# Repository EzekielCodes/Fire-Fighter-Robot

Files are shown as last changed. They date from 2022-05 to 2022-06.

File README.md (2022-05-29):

# 2122PROJBRANDBLUSROBOT

## Getting started

To make it easy for you to get started with GitLab, here's a list of recommended next steps.

Already a pro? Just edit this README.md and make it your own. Want to make it easy? [Use the template at the bottom](#editing-this-readme)!

## Add your files

- [ ] [Create](https://docs.gitlab.com/ee/user/project/repository/web_editor.html#create-a-file) or [upload](https://docs.gitlab.com/ee/user/project/repository/web_editor.html#upload-a-file) files
- [ ] [Add files using the command line](https://docs.gitlab.com/ee/gitlab-basics/add-file.html#add-a-file-using-the-command-line) or push an existing Git repository with the following command:

```
cd existing_repo
git remote add origin https://gitlab.com/ikdoeict/toluwani.akindele/2122projbrandblusrobot.git
git branch -M main
git push -uf origin main
```

## Integrate with your tools

- [ ] [Set up project integrations](https://gitlab.com/ikdoeict/toluwani.akindele/2122projbrandblusrobot/-/settings/integrations)

## Collaborate with your team

- [ ] [Invite team members and collaborators](https://docs.gitlab.com/ee/user/project/members/)
- [ ] [Create a new merge request](https://docs.gitlab.com/ee/user/project/merge_requests/creating_merge_requests.html)
- [ ] [Automatically close issues from merge requests](https://docs.gitlab.com/ee/user/project/issues/managing_issues.html#closing-issues-automatically)
- [ ] [Enable merge request approvals](https://docs.gitlab.com/ee/user/project/merge_requests/approvals/)
- [ ] [Automatically merge when pipeline succeeds](https://docs.gitlab.com/ee/user/project/merge_requests/merge_when_pipeline_succeeds.html)

## Test and Deploy

Use the built-in continuous integration in GitLab.

- [ ] [Get started with GitLab CI/CD](https://docs.gitlab.com/ee/ci/quick_start/index.html)
- [ ] [Analyze your code for known vulnerabilities with Static Application Security Testing(SAST)](https://docs.gitlab.com/ee/user/application_security/sast/)
- [ ] [Deploy to Kubernetes, Amazon EC2, or Amazon ECS using Auto Deploy](https://docs.gitlab.com/ee/topics/autodevops/requirements.html)
- [ ] [Use pull-based deployments for improved Kubernetes management](https://docs.gitlab.com/ee/user/clusters/agent/)
- [ ] [Set up protected environments](https://docs.gitlab.com/ee/ci/environments/protected_environments.html)

***

# Editing this README

When you're ready to make this README your own, just edit this file and use the handy template below (or feel free to structure it however you want - this is just a starting point!).  Thank you to [makeareadme.com](https://www.makeareadme.com/) for this template.

## Suggestions for a good README
Every project is different, so consider which of these sections apply to yours. The sections used in the template are suggestions for most open source projects. Also keep in mind that while a README can be too long and detailed, too long is better than too short. If you think your README is too long, consider utilizing another form of documentation rather than cutting out information.

## Name
Choose a self-explaining name for your project.

## Description
Let people know what your project can do specifically. Provide context and add a link to any reference visitors might be unfamiliar with. A list of Features or a Background subsection can also be added here. If there are alternatives to your project, this is a good place to list differentiating factors.

## Badges
On some READMEs, you may see small images that convey metadata, such as whether or not all the tests are passing for the project. You can use Shields to add some to your README. Many services also have instructions for adding a badge.

## Visuals
Depending on what you are making, it can be a good idea to include screenshots or even a video (you'll frequently see GIFs rather than actual videos). Tools like ttygif can help, but check out Asciinema for a more sophisticated method.

## Installation
Within a particular ecosystem, there may be a common way of installing things, such as using Yarn, NuGet, or Homebrew. However, consider the possibility that whoever is reading your README is a novice and would like more guidance. Listing specific steps helps remove ambiguity and gets people to using your project as quickly as possible. If it only runs in a specific context like a particular programming language version or operating system or has dependencies that have to be installed manually, also add a Requirements subsection.

## Usage
Use examples liberally, and show the expected output if you can. It's helpful to have inline the smallest example of usage that you can demonstrate, while providing links to more sophisticated examples if they are too long to reasonably include in the README.

## Support
Tell people where they can go to for help. It can be any combination of an issue tracker, a chat room, an email address, etc.

## Roadmap
If you have ideas for releases in the future, it is a good idea to list them in the README.

## Contributing
State if you are open to contributions and what your requirements are for accepting them.

For people who want to make changes to your project, it's helpful to have some documentation on how to get started. Perhaps there is a script that they should run or some environment variables that they need to set. Make these steps explicit. These instructions could also be useful to your future self.

You can also document commands to lint the code or run tests. These steps help to ensure high code quality and reduce the likelihood that the changes inadvertently break something. Having instructions for running tests is especially helpful if it requires external setup, such as starting a Selenium server for testing in a browser.

## Authors and acknowledgment
Show your appreciation to those who have contributed to the project.

## License
For open source projects, say how it is licensed.

## Project status
If you have run out of energy or time for your project, put a note at the top of the README saying that development has slowed down or stopped completely. Someone may choose to fork your project or volunteer to step in as a maintainer or owner, allowing your project to keep going. You can also make an explicit request for maintainers.

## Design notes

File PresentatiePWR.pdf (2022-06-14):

# BESTUURBARE BRANDBLUSROBOT

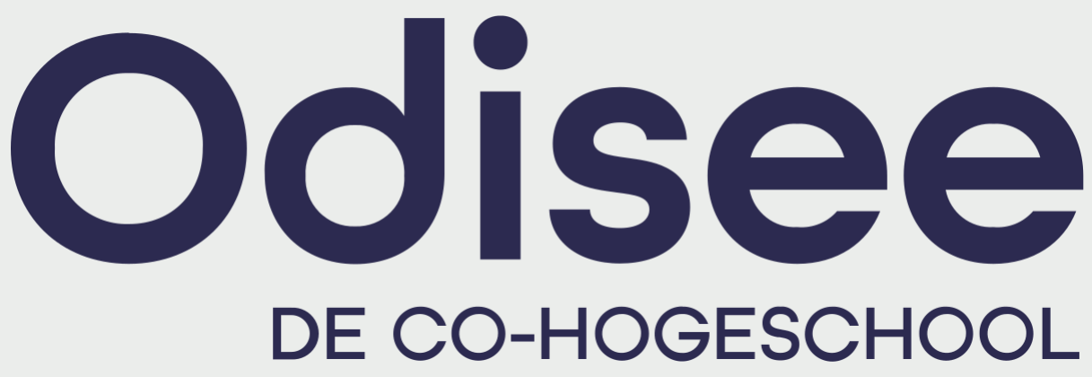
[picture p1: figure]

## Toluwani Akindele

## Vito Beké

## Michiel Decrock

## Lukas Rabaey

B es tuu r ba r e b randbl us r o bo t | 13-06-2022 | 1

## Project & wetenschappelijk rapporteren

## Groep: ICTEO12

# Inhoud

## - Besturing / aandrijving

## - Sensoren

## - Visualisatie, app

## - Waterreservoir

## - PCB

## - Lasercutten

## - Problemen

## - Optimalisatie

## - Demo

B es tuu r ba r e b ran dbl us r o bo t | 13-06-2022 | 2

# Besturing / aandrijving

## - PS2-controller

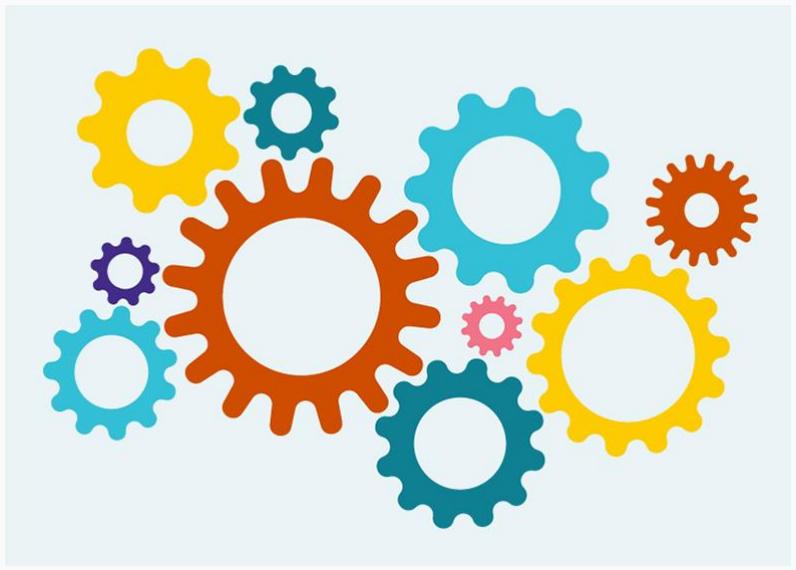
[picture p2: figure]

## - DC-motor

## - Stappenmotor

## - Waterpomp

B es tuu r ba r e b ran dbl us r o bo t | 13-06-2022 | 3

# PS2-controller

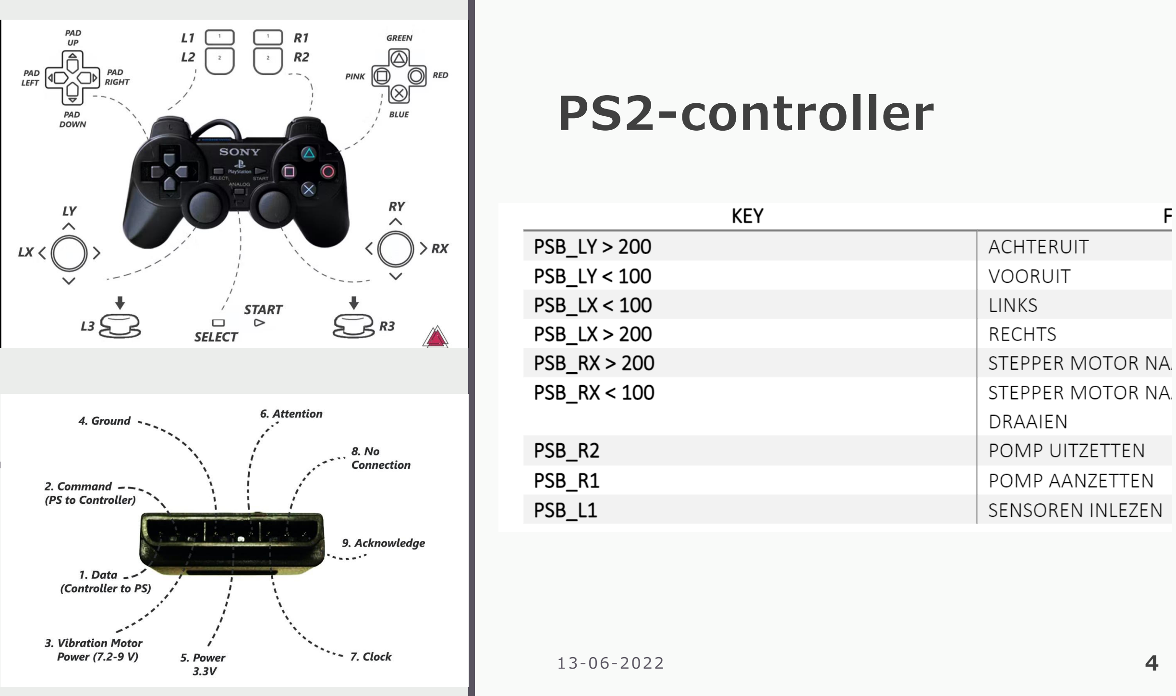
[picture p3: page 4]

13-06-2022 | 4

# DC-motor

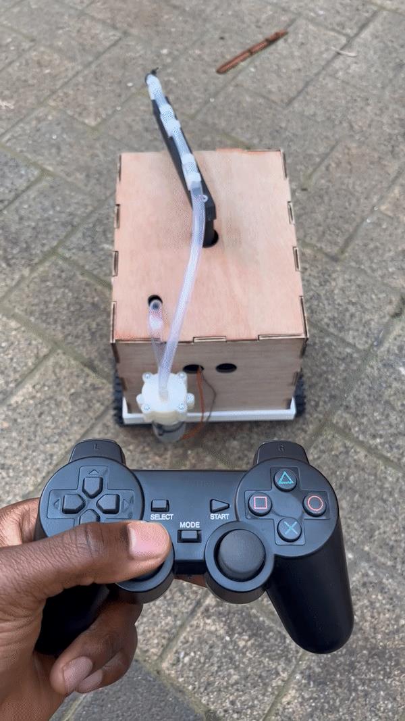
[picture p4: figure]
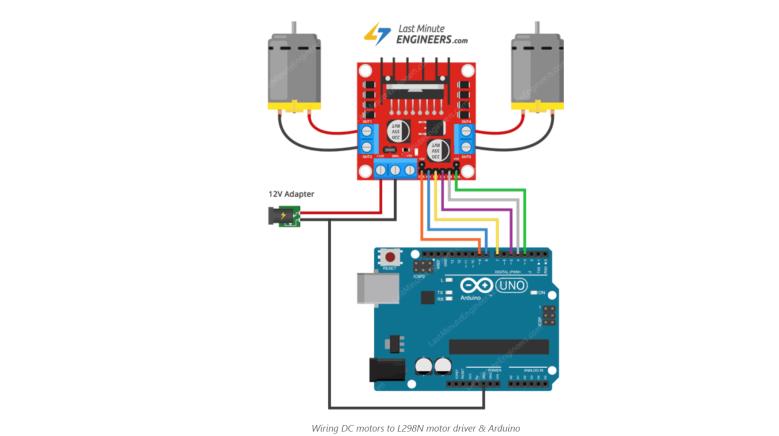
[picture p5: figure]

# Stappenmotor

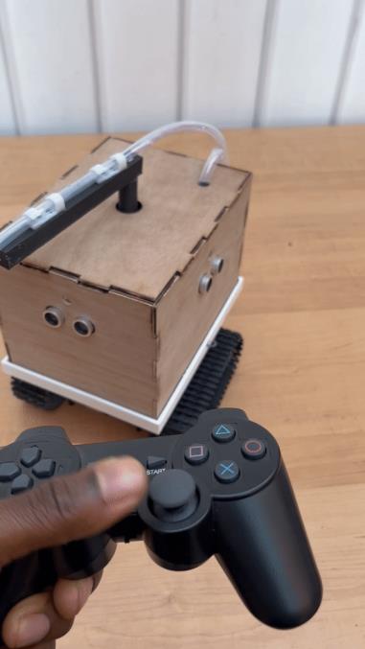
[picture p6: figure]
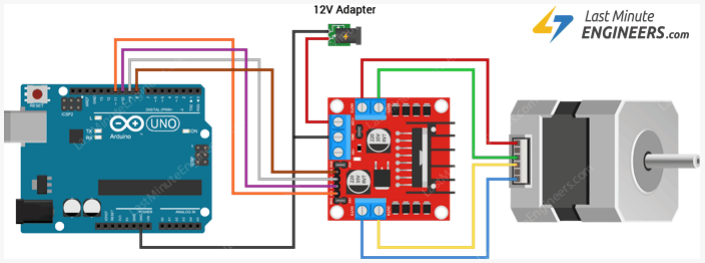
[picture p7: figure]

# Waterpomp

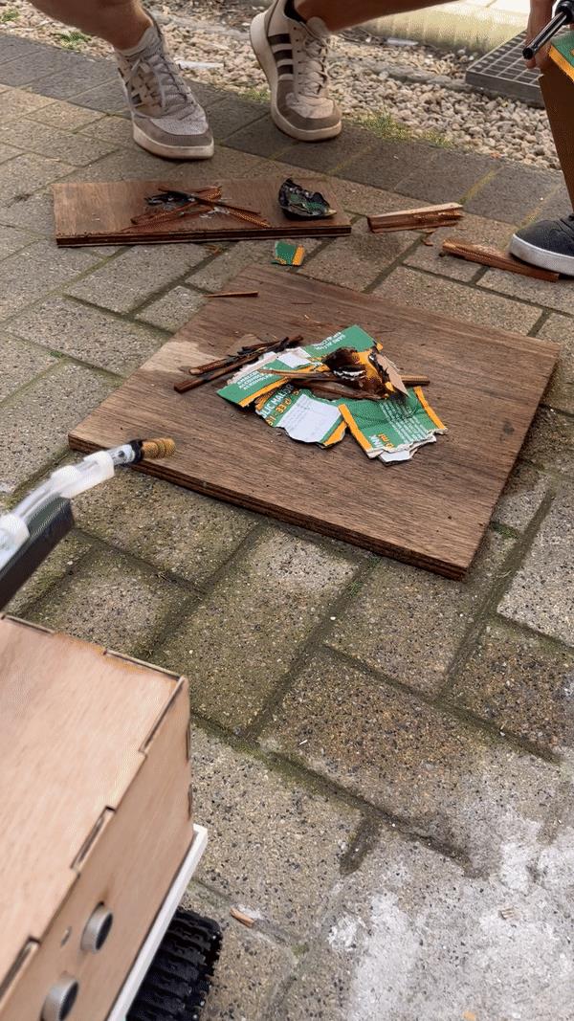
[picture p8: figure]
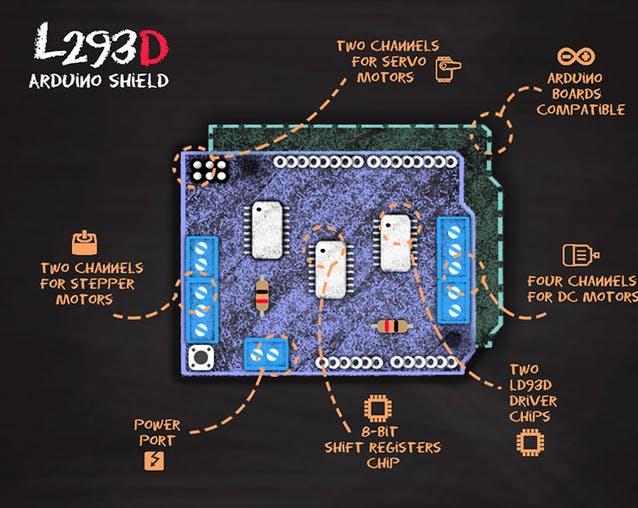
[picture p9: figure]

# Sensoren

## - HC-SR05 ultrasonic

## sensor

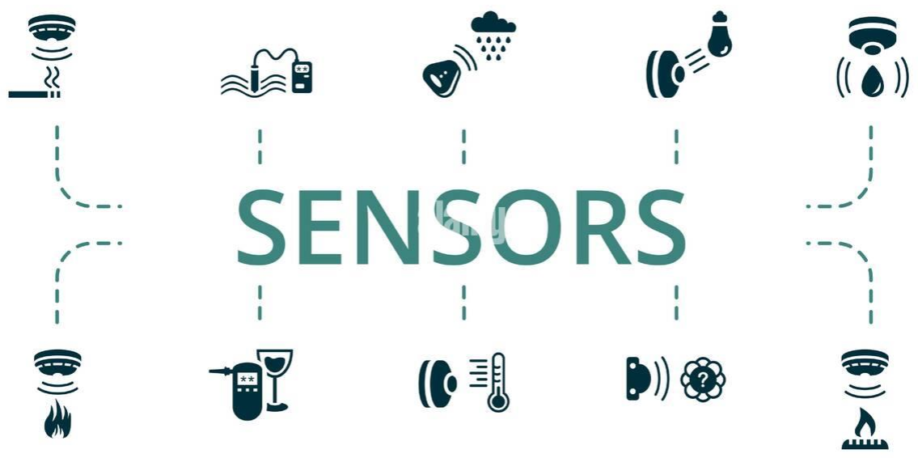
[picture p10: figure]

## - MLX90614

B es tuu r ba r e b ran dbl us r o bo t | 13-06-2022 | 8

# HC-SR05 ultrasonic sensor

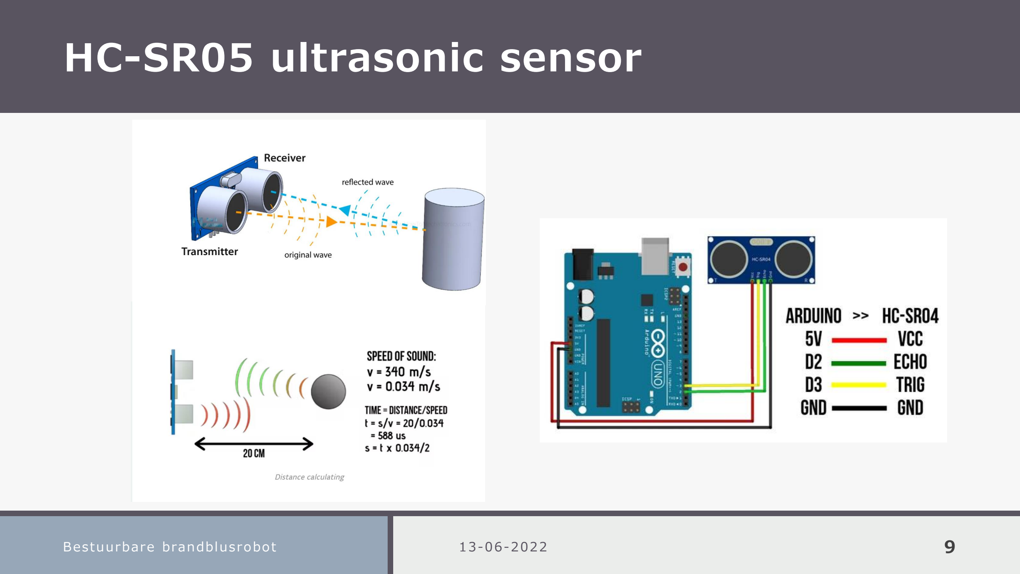
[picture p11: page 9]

# MLX90614

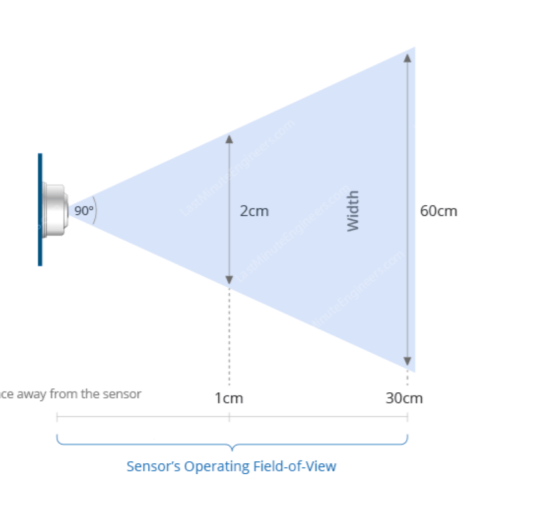
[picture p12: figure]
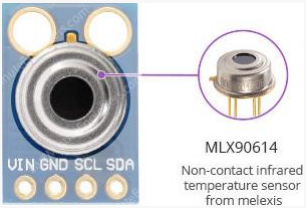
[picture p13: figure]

## - Visualisatie

# - App

- HC-05-

## bluetoothmodule

B es tuu r ba r e b ran dbl us r o bo t | 13-06-2022 | 11

# Visualisatie / app

# Visualisatie

## Connectiemethode: Bluetooth

## - goedkoop

## - ef ficiënter energieverbruik

## (tegenover wifi)

## - PoC: geen groot

## signaalbereik nodig

# App

## - MIT App Inventor

## - eenvoudig programmeren

## - Android app

# App

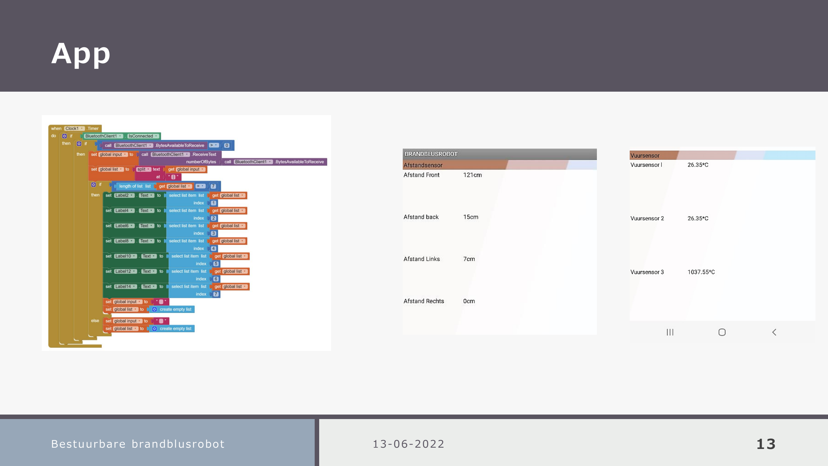
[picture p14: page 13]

# Bluetoothmodule

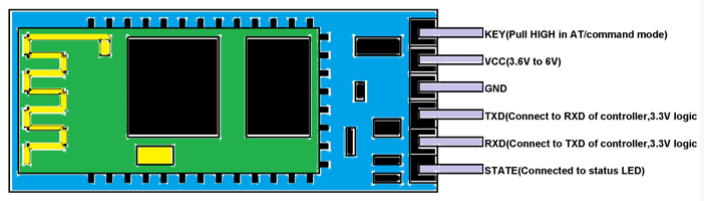
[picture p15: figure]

## HC-05-bluetoothmodule

## - Sof twareSerial library

## - Sensoren → Arduino →

## BT module → App

## (component)

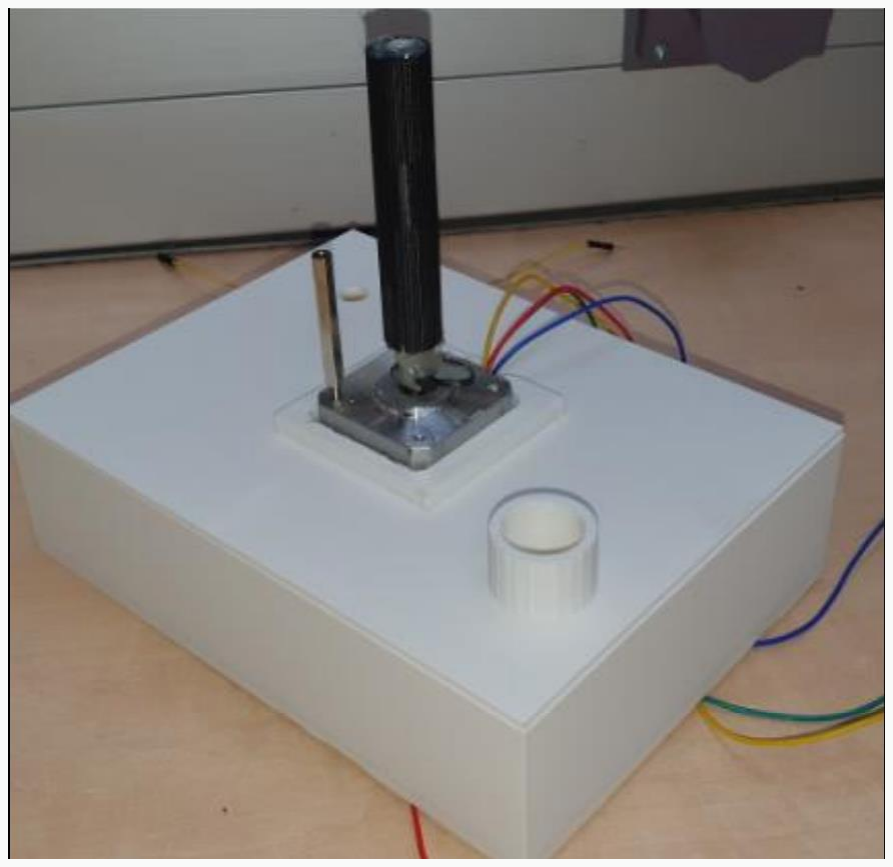
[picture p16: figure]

B es tuu r ba r e b ran dbl us r o bo t | 13-06-2022 | 15

# Waterreservoir

# Waterreservoir

## - PLA

## - 5,0 mm dikte buitenranden

## - Nozzle: 0,5 mm

## - Siliconenspray

## - Inhoud: +/- 0,5L

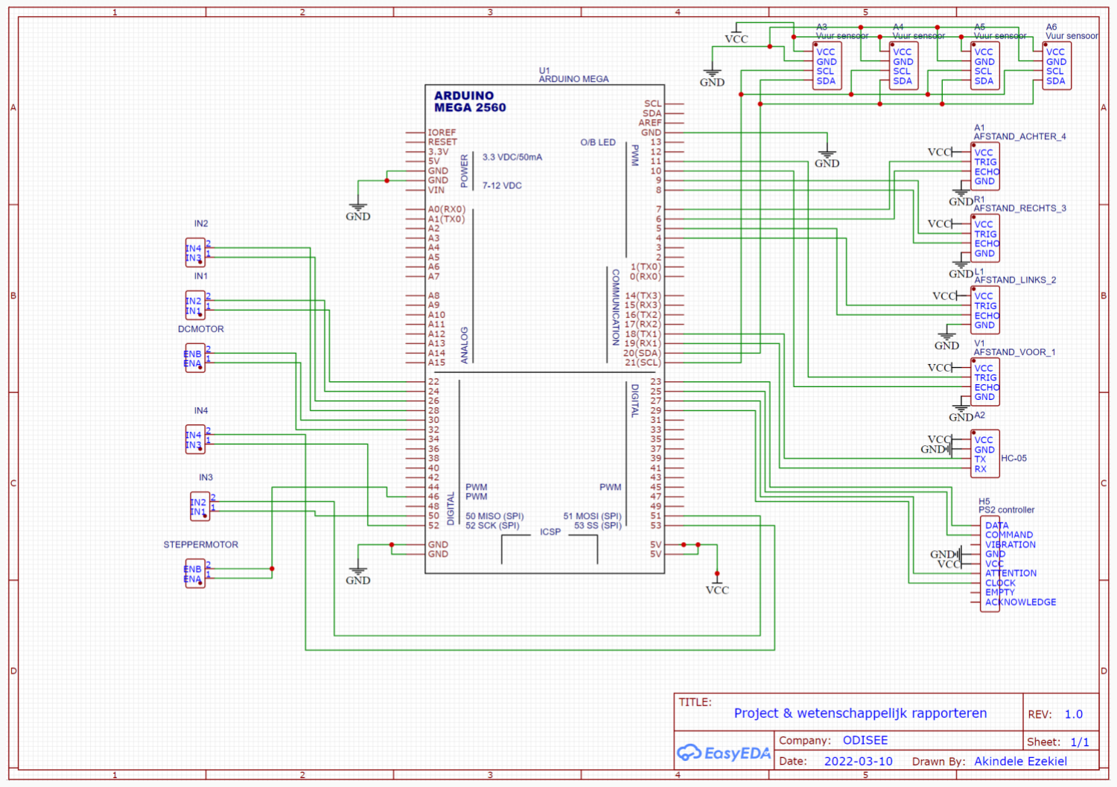
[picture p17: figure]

B es tuu r ba r e b ran dbl us r o bo t | 13-06-2022 | 17

# Schakeling

## - PCB

## - Schema

# PCB

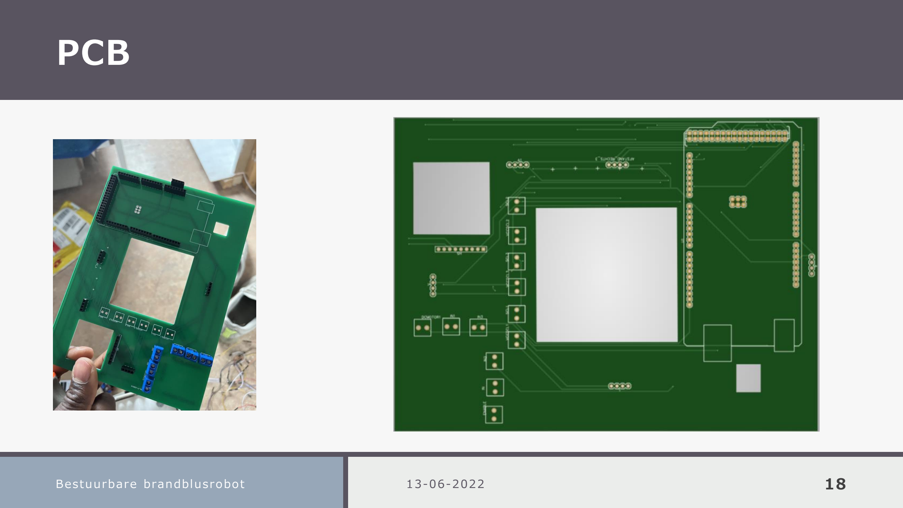
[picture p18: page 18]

# Schema

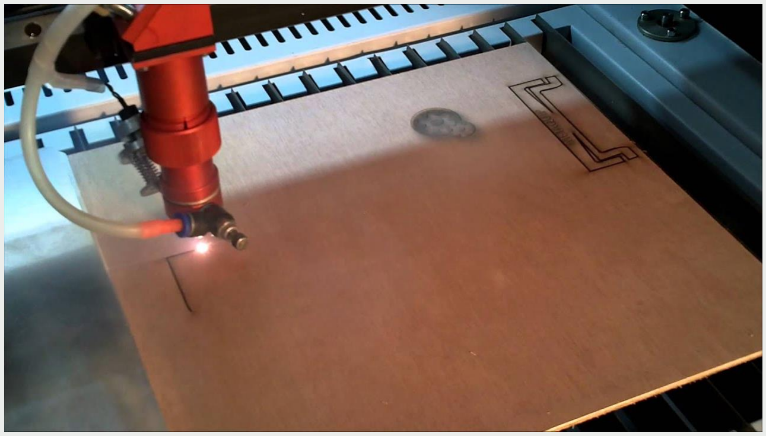
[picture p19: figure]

Bestuurbare brandblusrobot | 20

# Lasercutten

13-06-2022

# Fusion 360

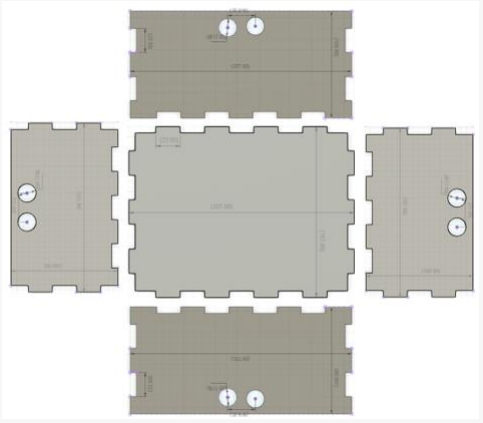
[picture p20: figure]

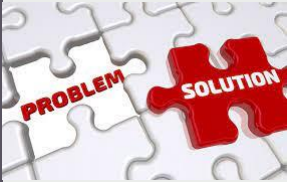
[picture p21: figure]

B es tuu r ba r e b ran dbl us r o bo t | 13-06-2022 | 22

# Problemen

## Waarop zijn we gestoten?

## - Behuizing

## - Vuursensor

## - Afstandssensor

# - App

## - Stappenmotor

# Optimalisatie

## Wat kan er nog worden verbeterd?

## - Aandrijving

## - Sensoren

## - Blusonderdelen

# - App

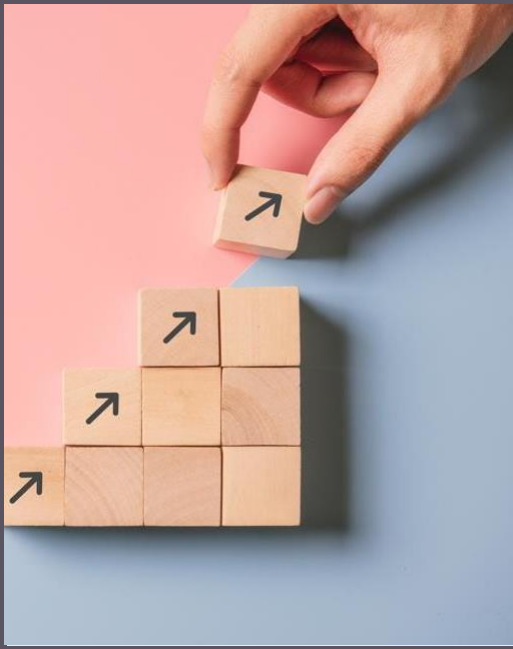
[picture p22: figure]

B es tuu r ba r e b ran dbl us r o bo t | 13-06-2022 | 23

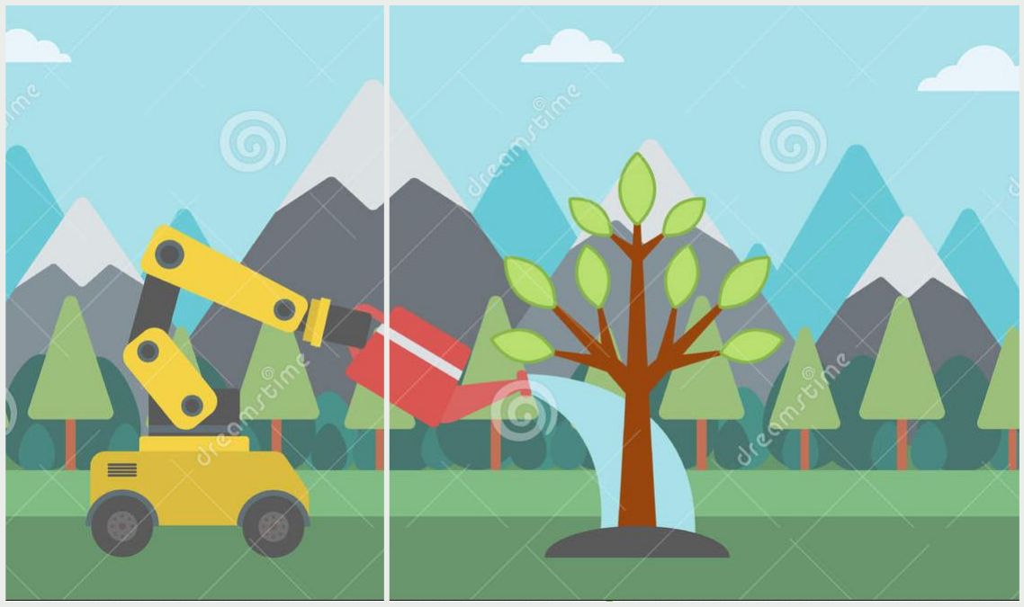
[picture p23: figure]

# “Het is precies eerder om planten water te geven”

# Demo

## Demo video brandblusrobot (https://www.youtube.com/watch?v=nROR7IA7b1U)

B es tuu r ba r e b ran dbl us r o bo t | 13-06-2022 | 25

# BEDANKT

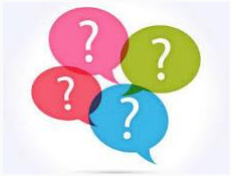
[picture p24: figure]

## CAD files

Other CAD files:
CorrecteBOX_v5.f3d
LasercutBOX_36mmdikte.f3d
water_reservoir.skp

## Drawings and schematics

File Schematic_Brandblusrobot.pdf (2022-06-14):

## ARDUINO MEGA 2560

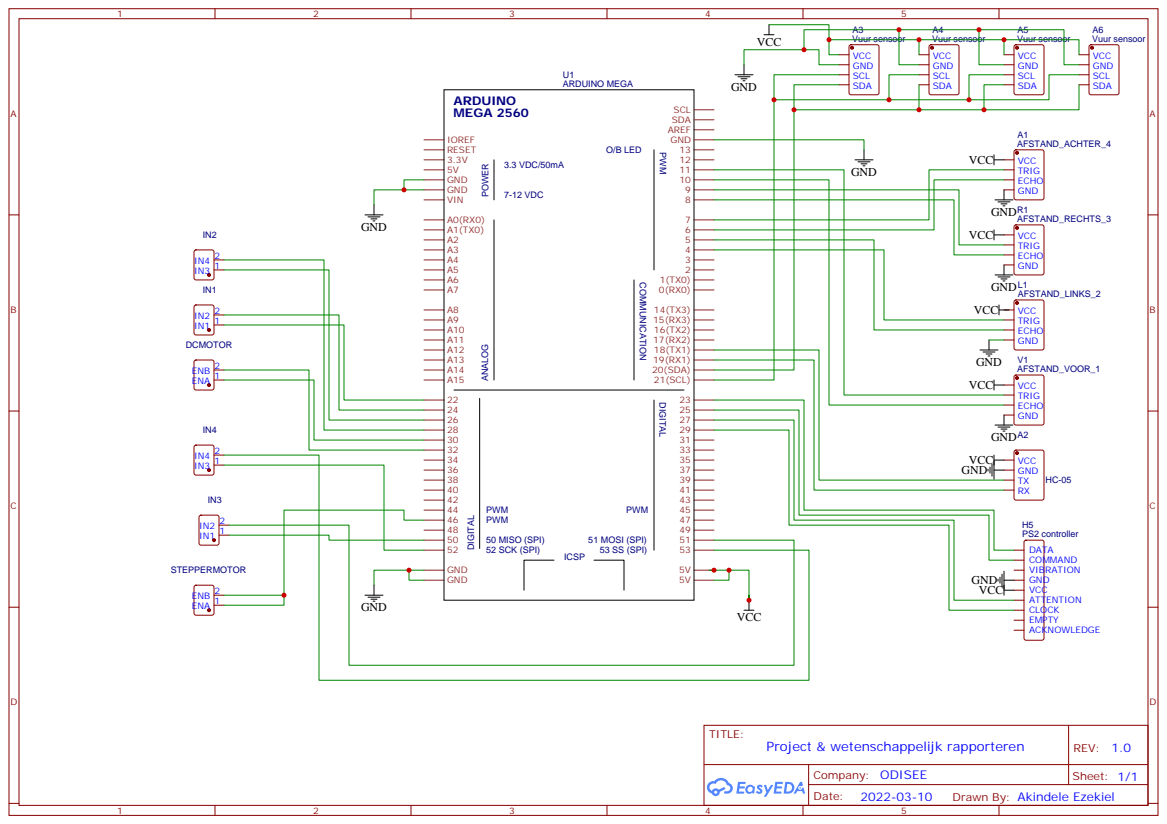
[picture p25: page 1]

Drawn By: Akindele Ezekiel

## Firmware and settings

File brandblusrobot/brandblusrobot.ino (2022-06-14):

/*
   bluetooth + afstand
*/

// pinnen voor de afstand sensoren
int Lecho1 = 40; //links echo
int Ltrig1 = 41; //links trig
int Fecho2 = 43; //forward echo
int Ftrig2 = 42; //forward trig
int Recho3 = 44; //rechts echo
int Rtrig3 = 45; //rechts trig
int Becho4 = 38; // niet meer nodig
int Btrig4 = 39; // niet meer nodig


int L_Distance = 0; // in deze varaible wordt de waarde van de afstand opgeslaan
int F_Distance = 0; // in deze varaible wordt de waarde van de afstand opgeslaan
int R_Distance = 0; // in deze varaible wordt de waarde van de afstand opgeslaan
int B_Distance = 0; // in deze varaible wordt de waarde van de afstand opgeslaan

#include <SoftwareSerial.h>
SoftwareSerial BTserial(19, 18); // RX | TX

/*
   vuur sensoor
*/

#include <Wire.h>
#include <Adafruit_MLX90614.h>

// adres van een van de temperatuur sensoren
// dezelfde pin maar hebben verschillende adressen
#define IR1 0x5B  
#define IR2 0x55
#define IR3 0x5A
// arduino functie
Adafruit_MLX90614 mlx; 

/*
   motor + ps2
*/

#define enA 53
#define in1 47
#define in2 49
#define in3 35
#define in4 37
#define enB 51
int LX = 0;
int LY = 0;
int RX = 0;
int RY = 0;
int len = 0;

#include <PS2X_lib.h>

int count = 1;
int error = 0;
byte type = 0;
byte vibrate = 0;
int check = 0;
PS2X ps2x;

/*
   stepper motor
*/

#include <Stepper.h>
const int stepsPerRevolution = 200; // change this to fit the number of steps per revolution
Stepper myStepper(stepsPerRevolution, 22, 23, 24, 25); //initialize the stepper library on pins 22 through 25:
const int enAStepper = 46;
const int enBStepper = 46;

/*
   water pomp
*/

#include <AFMotor.h>
AF_DCMotor pump(2);

void setup() {

  /*
     stepper motor
  */

  analogWrite(enAStepper, 255);
  analogWrite(enBStepper, 255);
  myStepper.setSpeed(60);

  /*
     ps2
  */

  Serial.begin(9600);
  //setup pins and settings:  GamePad(clock, command, attention, data, Pressures?, Rumble?) check for error
  error = ps2x.config_gamepad(31, 32, 33, 34, true, true); 
  type = ps2x.readType();

  if (error == 0) {
    Serial.println("Found Controller, configured successful");
  }
  else if (error == 1)
    Serial.println("No controller found, check wiring or reset the Arduino");
  else if (error == 2)
    Serial.println("Controller found but not accepting commands");
  else if (error == 3)
    Serial.println("Controller refusing to enter Pressures mode, may not support it.");

  // Check for type of controller
  type = ps2x.readType();
  switch (type) {
    case 0:
      Serial.println("Unknown Controller type");
      break;
    case 1:
      Serial.println("DualShock Controller Found");
      break;
    case 2:
      Serial.println("GuitarHero Controller Found");
      break;
  }

  /*
     afstand
  */

  //obstacle sensor
  pinMode(Ltrig1, OUTPUT);
  pinMode(Lecho1, INPUT);
  pinMode(Ftrig2, OUTPUT);
  pinMode(Fecho2, INPUT);
  pinMode(Rtrig3, OUTPUT);
  pinMode(Recho3, INPUT);

  BTserial.begin(9600);
  pinMode(Btrig4, OUTPUT);
  pinMode(Becho4, INPUT);

  /*
     motoren
  */

  pinMode(enA, OUTPUT);
  pinMode(in1, OUTPUT);
  pinMode(in2, OUTPUT);
  pinMode(in3, OUTPUT);
  pinMode(in4, OUTPUT);

  /*
     vuur
  */

  mlx.begin(); // functie beginnen
}

/*
   Methode voor afstandsensoren
*/

// methode voor de linkse afstand te berekenen

int L_Distance_test() {
  digitalWrite(Ltrig1, LOW);
  delayMicroseconds(2);
  digitalWrite(Ltrig1, HIGH);
  delayMicroseconds(10);
  digitalWrite(Ltrig1, LOW);
  float Ldistance = pulseIn(Lecho1, HIGH);
  delay(10);

  Ldistance = Ldistance  * 0.034 / 2;
  return (int)Ldistance;
}

// methode voor de forward afstand te berekenen

int F_Distance_test() {
  digitalWrite(Ftrig2, LOW);
  delayMicroseconds(2);
  digitalWrite(Ftrig2, HIGH);
  delayMicroseconds(10);
  digitalWrite(Ftrig2, LOW);
  float Fdistance = pulseIn(Fecho2, HIGH);
  delay(10);

  Fdistance = Fdistance  * 0.034 / 2;
  return (int)Fdistance;
}

// methode voor de rechtse afstand te berekenen

int B_Distance_test() {
  digitalWrite(Btrig4, LOW);
  delayMicroseconds(2);
  digitalWrite(Btrig4, HIGH);
  delayMicroseconds(10);
  digitalWrite(Btrig4, LOW);
  float Bdistance = pulseIn(Becho4, HIGH);
  delay(10);

  Bdistance = Bdistance  * 0.034 / 2;
  return (int)Bdistance;
}

// methode voor de rechtse afstand te berekenen

int R_Distance_test() {
  digitalWrite(Rtrig3, LOW);
  delayMicroseconds(2);
  digitalWrite(Rtrig3, HIGH);
  delayMicroseconds(10);
  digitalWrite(Rtrig3, LOW);
  float Rdistance = pulseIn(Recho3, HIGH);
  delay(10);

  Rdistance = Rdistance  * 0.034 / 2;
  return (int)Rdistance;
}

/*
   methode voor motoren
*/

void forward()
{
  analogWrite(enA, 200);
  analogWrite(enB, 200);
  digitalWrite(in1, HIGH);
  digitalWrite(in2, LOW);
  digitalWrite(in3, LOW);
  digitalWrite(in4, HIGH);
}

void backward()
{
  analogWrite(enA, 200);
  analogWrite(enB, 200);
  digitalWrite(in1, LOW);
  digitalWrite(in2, HIGH);
  digitalWrite(in3, HIGH);
  digitalWrite(in4, LOW);
}

void right()
{
  analogWrite(enA, 255);
  analogWrite(enB, 80);
  digitalWrite(in1, LOW);
  digitalWrite(in2, HIGH);
  digitalWrite(in3, HIGH);
  digitalWrite(in4, LOW);
}

void left()
{
  analogWrite(enA, 80);
  analogWrite(enB, 255);
  digitalWrite(in1, LOW);
  digitalWrite(in2, HIGH);
  digitalWrite(in3, HIGH);
  digitalWrite(in4, LOW);
}

void stopm() {
  analogWrite(enA, 0);
  analogWrite(enB, 0);
  digitalWrite(in1, LOW);
  digitalWrite(in2, LOW);
  digitalWrite(in3, LOW);
  digitalWrite(in4, LOW);

}

/*
   Methode stepper motor
*/

void setStepperIdle() {
  digitalWrite(50, LOW);
  digitalWrite(51, LOW);
  digitalWrite(52, LOW);
  digitalWrite(53, LOW);
}

void StepperPwmOff() {
  analogWrite(enAStepper, 0);
  analogWrite(enBStepper, 0);
}

void StepperPwmOn() {
  analogWrite(enAStepper, 255);
  analogWrite(enBStepper, 255);
}

void pumpstart() {
  pump.setSpeed(255);
  pump.run(FORWARD);
}
void pumpstop() {
  pump.setSpeed(0);
  pump.run(RELEASE);
}

void loop()
{
  if (error == 1) {
    //skip loop if no controller found
  }
  else {
    ps2x.read_gamepad(false, vibrate);
    delay(50);

    //receive values from p22 joystick
    LY = ps2x.Analog(PSS_LY);                     
    LX = ps2x.Analog(PSS_LX);

    RY = ps2x.Analog(PSS_RY);
    RX = ps2x.Analog(PSS_RX);

    stopm();
    setStepperIdle();

    //check if the joystick pushed up side
    if (LY > 200)                      
    {
      forward();
      Serial.println("Back");
    }

    if ((LY < 100 ) && (LX != 0))
    {
      backward();
      Serial.println("for");
      Serial.println(LY);
    }

    if ((LX < 100 ) && (LY != 0))
    {
      right();
      Serial.println("left");
      Serial.println(LX);
    }
    if (LX > 200 )
    {
      left();
      Serial.println("right");
    }
    if (RX > 200) {
      StepperPwmOn();
      myStepper.step(-5);
      StepperPwmOff();
      setStepperIdle();
      Serial.println("turn left");
    }

    if ((RX < 100)  && (LY != 0)) {
      StepperPwmOn();
      myStepper.step(5);
      StepperPwmOff();
      setStepperIdle();
      Serial.println("turn right");
      Serial.println(RX);
    }

    if (ps2x.ButtonPressed(PSB_R1)) {
      Serial.println("pump_start");
      pumpstart();
    }

    if (ps2x.ButtonPressed(PSB_R2)) {
      Serial.println("pump_stop");
      pumpstop();
    }

    if (ps2x.ButtonPressed(PSB_L1))
    {
      Serial.println("press");
      count = 1;
      while (count < 10)
      {
        count++;
        Serial.println(count);

        /*
          bluetooth
        */

        R_Distance = R_Distance_test();//hier wordt de afstand bepaald
        L_Distance = L_Distance_test();//hier wordt de afstand bepaald
        B_Distance = B_Distance_test();//hier wordt de afstand bepaald
        F_Distance = F_Distance_test();//hier wordt de afstand bepaald

 	      /*
          vuur sensor
        */ 

        mlx.AddrSet(IR1); // adres set sensor 1
        mlx.temp1 = mlx.readObjectTempC(); // temperatuur lezen sensor 1

        mlx.AddrSet(IR2); // adres set sensor 2
        mlx.temp2 = mlx.readObjectTempC(); // temperatuur lezen sensor 2

        mlx.AddrSet(IR3); // adres set sensor 3
        mlx.temp3 = mlx.readObjectTempC(); // temperatuur lezen sensor 3
        
        BTserial.print(F_Distance);
        BTserial.print("cm");
        BTserial.print("|");

        BTserial.print(B_Distance);
        BTserial.print("cm");
        BTserial.print("|");

        BTserial.print(L_Distance);
        BTserial.print("cm");
        BTserial.print("|");

        BTserial.print(R_Distance);
        BTserial.print("cm");
        BTserial.print("|");

        BTserial.print(mlx.temp1);
        BTserial.print("*C");
        BTserial.print("|");

        BTserial.print(mlx.temp2);
        BTserial.print("*C");
        BTserial.print("|");

        BTserial.print(mlx.temp3);
        BTserial.print("*C");
        BTserial.print("|");

        delay(400);
      }
      LY = LX = 128; //return to default vlaues
      RY = RX = 128; //return to default values
    }
  }
}

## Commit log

2022-06-14 Update brandblusrobot/brandblusrobot.ino, water_reservoir.skp, PresentatiePWR.pdf Deleted Code_Final.ino
    [water_reservoir.skp]
2022-06-15 Update beschrijving.txt, LasercutBOX_36mmdikte.f3d, Trailer.mp4, Project brandblusrobot.mp4
    [LasercutBOX_36mmdikte.f3d]
